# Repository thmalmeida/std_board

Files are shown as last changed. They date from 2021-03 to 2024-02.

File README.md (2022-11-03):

# std_board
_std_board_ is an open hardware project that aims to bring the connectivity capacity of a microcontroller joining with sensors and actuators to a remote monitoring and control.

Renderized PCB with electrical components and modules are showed on the following picture.
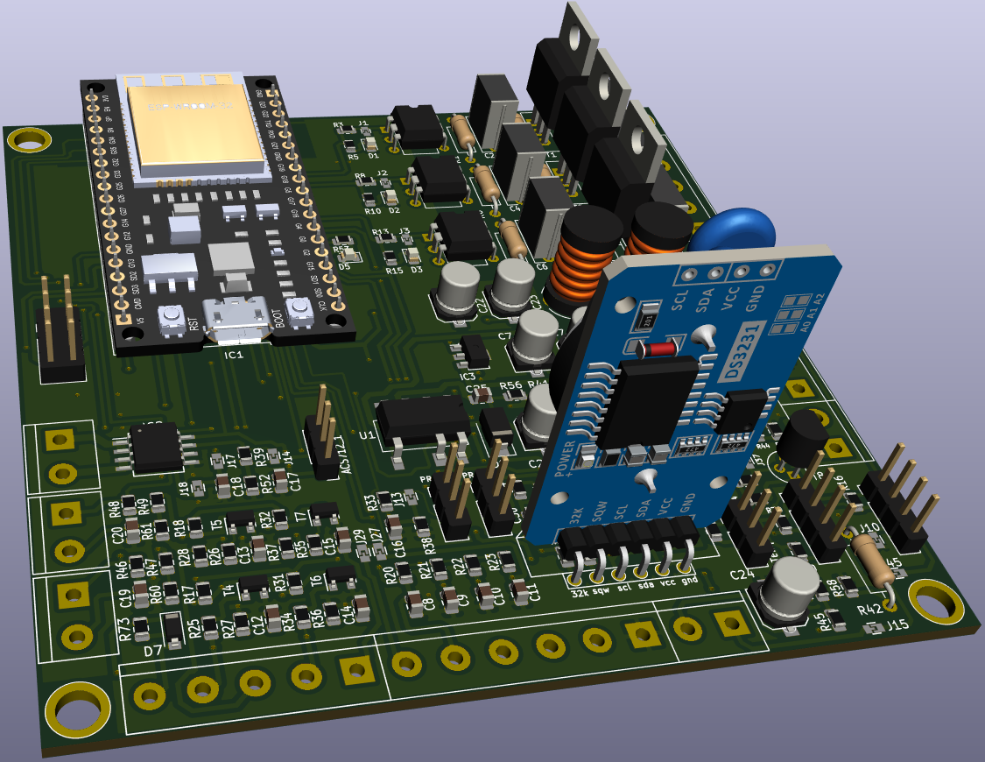
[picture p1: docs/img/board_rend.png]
std_board_img03


# update logs

- 20210901
  + Voltage divider resistor values has been calculated sucessfully;
  + AC voltage measure sensor simulation has updated for 127 and 220 Vrms;
  + 

- 20210719
 - Fix voltage measure circuit on R58;
 - Modify voltage measure input borne to left side board avoid AC DC short circuits

# Content

* [About std_board](#about-std_board)
* [Features](#features)
* [Peripherals mapping](#peripherals-mapping)
* [Digital inputs](#digitadigitall-inputs)
* [Level sensor](#level-sensor)
* [Voltage sensor](#voltage-sensor)
* [Power input modes](#power_input_modes)
  + [Mode 1: 120-240 VAC input](#mode-1-120-240-vac-input)
  + [Mode 2: 24 VAC input](#mode-2-24-vac-input)
  + [Mode 3: 5 Vdc (external power supply)](#mode-3-5V)
* [Current controller](#current-controller)
* [AC load drive](#ac-load-drive)
* [Erros fixed on v0.1.0](#erros)

## About std_board

The main idea of std_board is help farmers to optimize production and monitoring some variables. Even this hardware is a little bit generic pplication that can control water pumps, valves, solenoids and any AC load. For this, it needs some feedback o real world physical variables like water weel level, time, water pressure inside pumps, ac voltage, ac current, thermal relay, and any digital input. The general purpose is optimize the production controlling the water flux.

The main concept of this system is interfaces one processor, e.g. ESP32, with electrical AC loads and physical parameters.
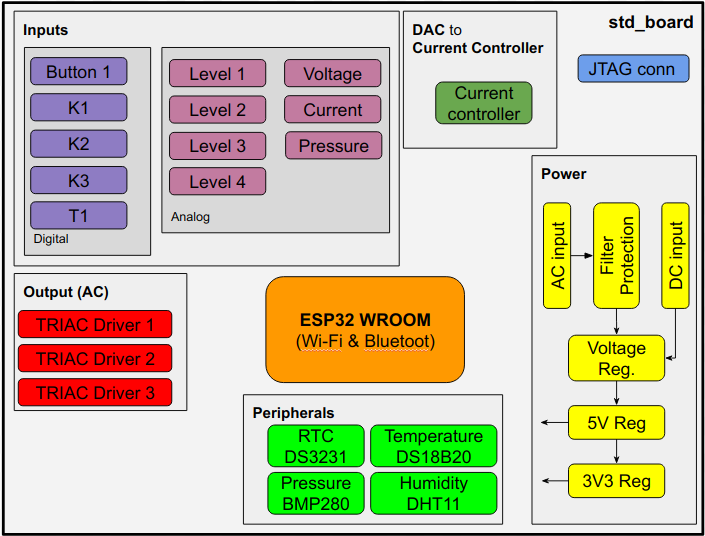
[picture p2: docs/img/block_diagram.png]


## Peripherals mapping

Pin map table of ESP32 onboard connections
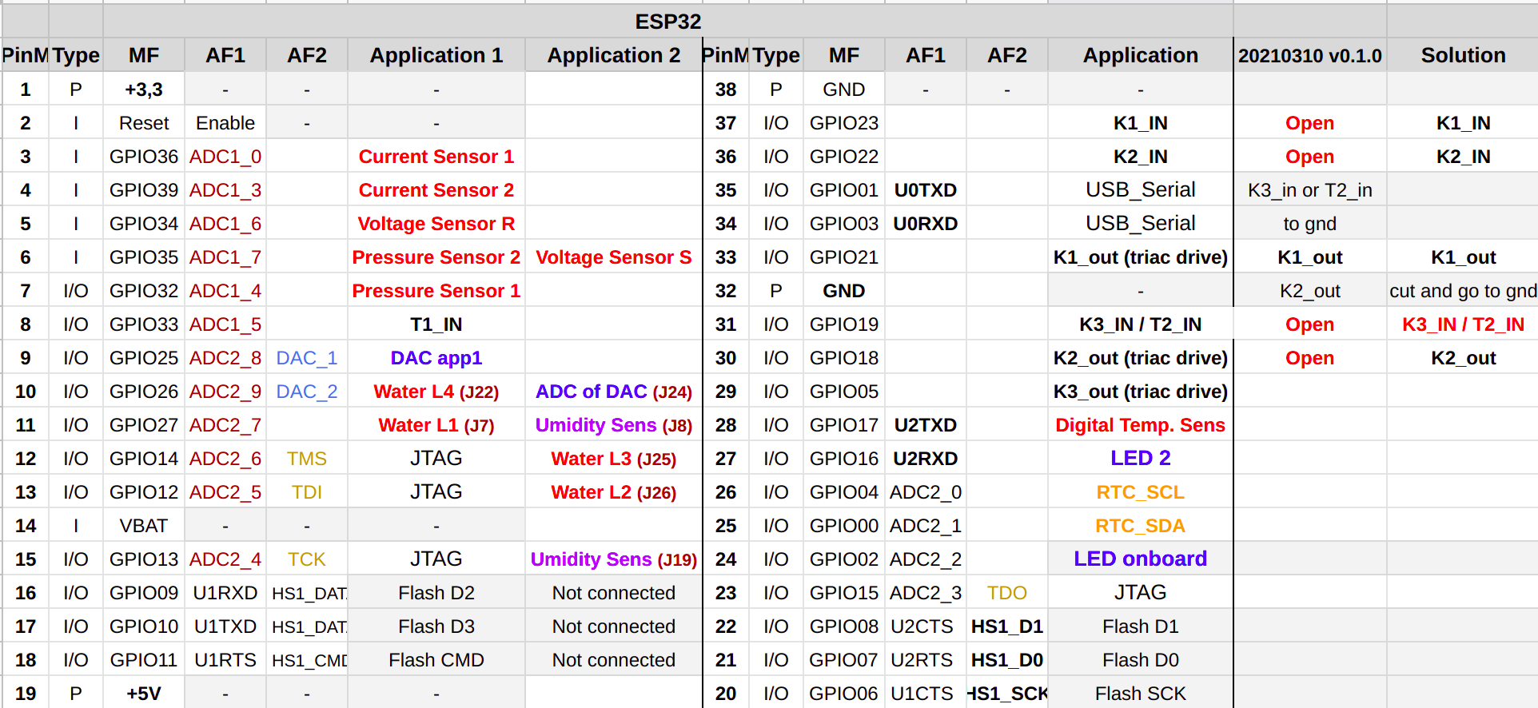
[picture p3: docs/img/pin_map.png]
.

The onboard system has the following connectivities:
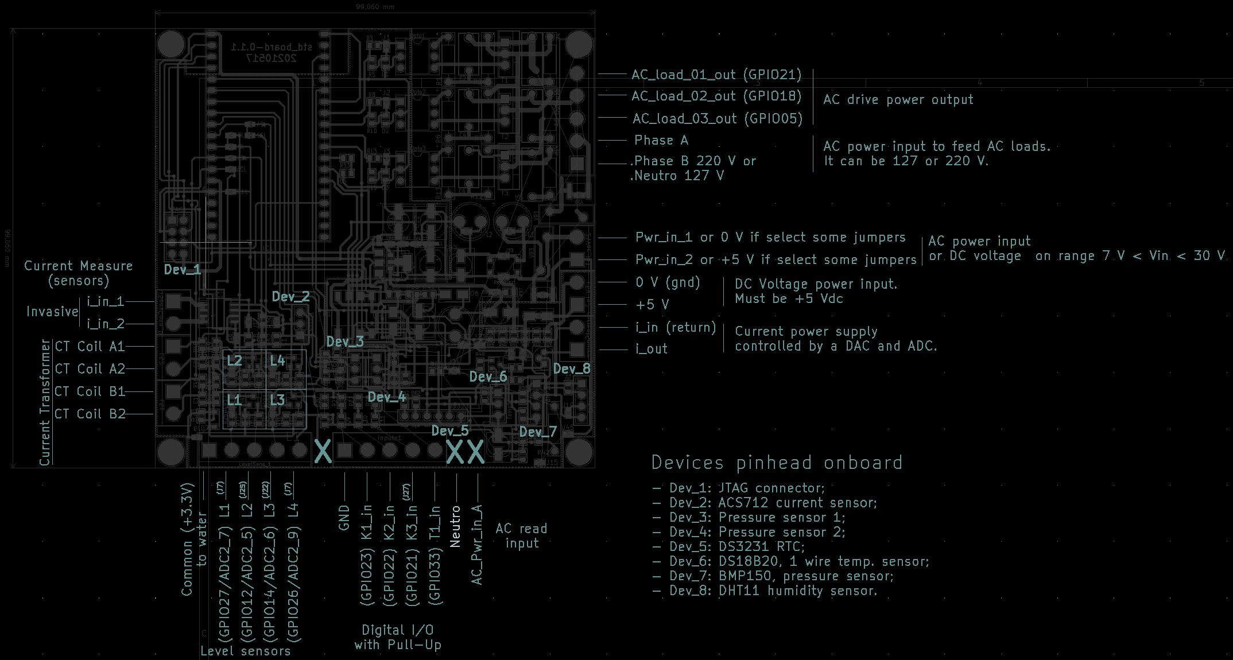
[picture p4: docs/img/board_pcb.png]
std_board_img02


## Features
This board has few hardware printed circuits that interfaces the ESP32 with real world variables conditioning physical variables to low voltages signals readable for input micro controller.

* Digital I/O (four)
* Input for pressure sensor;
* Input for temperature one wire temperature sensor (e.g. DS18B20);
* Umidity sensor DHT11;
* Current controller using internal DAC and onboard circuit processing;
* Protection circuit;
* AC voltage sensor;
* AC current sensor;
* AC load drive;
* JTAG connector - for debbugger (e.g. FT2232H);
* I2C connection for RTC module (e.g. DS3231);
* I2C connection for barometric sensor (e.g. BMP280);
* Four independent water level sensor circuits;
* Onboard LED indicator;
* Power supply with capability with different voltage levels input;

### Digital I/O

Four digital I/O are mounted with 56 kOhms pull up resistors and low pass filter using 47 nF capactitor. The circuit are showing on the following Figure.

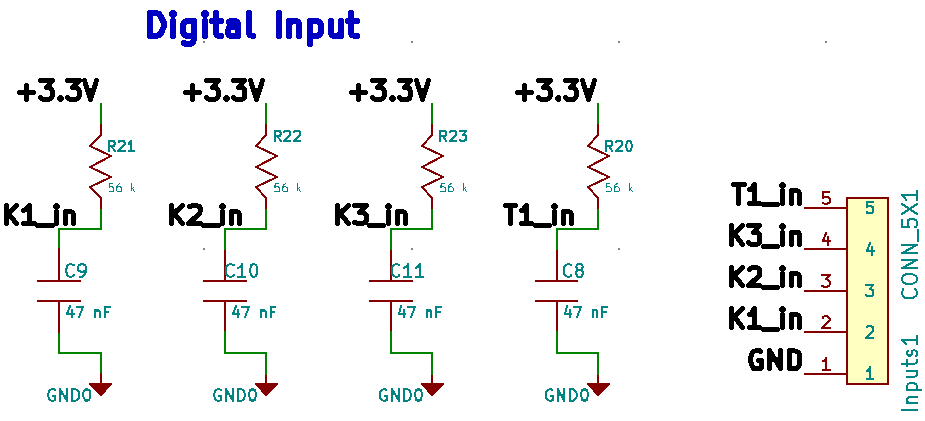
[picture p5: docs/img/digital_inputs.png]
Image of main window on linux


### Level sensor

This board has four independent water level sensor circuit. Each circuit uses one BJT (bipolar junction transistor) and has one jump to exclude this transistor if desired. The main concept of this circuit a voltage division with amplification. The transistor has the function to amplifier the signal and transform it in a digital.

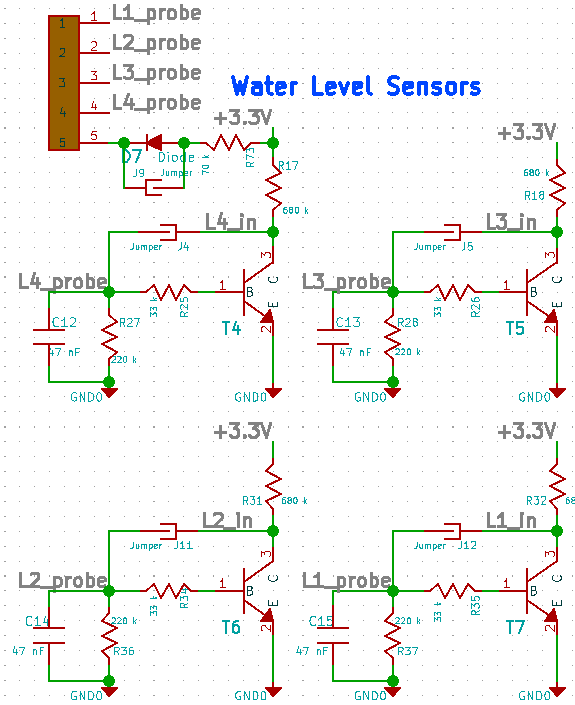
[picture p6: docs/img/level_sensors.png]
Level_Sensors_img01 Water level sensor schematic circuit


Some simulation has been done

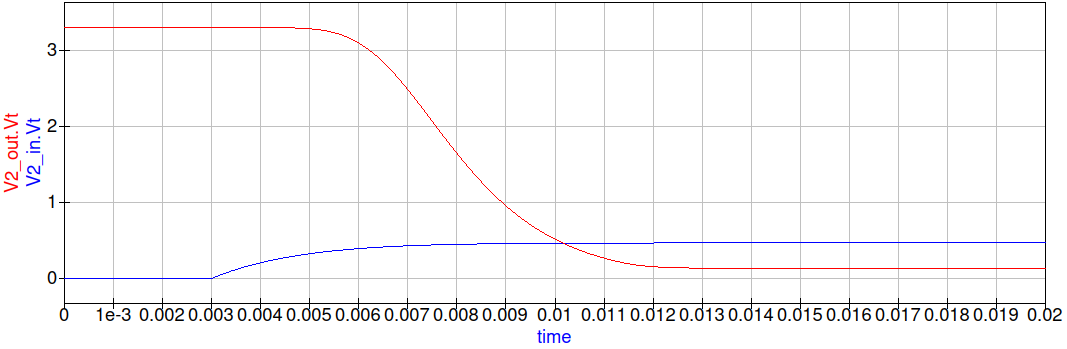
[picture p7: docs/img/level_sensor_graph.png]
Level_Sensors_img02 Time domain input and output voltage level


## Voltage sensor
The voltage sensor can measure four different source of voltages into one selected soldering jump. The following Figure shows the schematic of voltage sensor circuit.

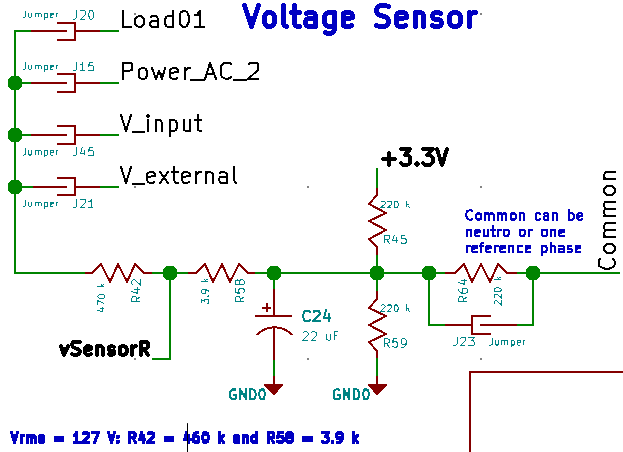
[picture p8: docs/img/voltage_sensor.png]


## Power input modes

### Mode 1: 120-240 VAC input
This mode
to 12VDC and 120 mA;
### Mode 2: 24 VAC to 5 VDC;
20211012 - This mode should be defined, calculated e design in a future moment. Linear regulation has a big waste on drop difference voltage when the input is ~40 V. Bests solutions were found using switching regulators. LNK30x series has bigger input AC voltage. Some candidates with low voltages are:

- LM2576
- LM2596
- DPA422GN
- XL7015

Switches regulators has best efficiency when drop difference voltage are considerable.

### Mode 3: 5 Vdc (external power supply)

If the system is powered with external 5 V power supply on Pwr_in_1 (0V) and Pwr_in_2 (+5V), it needs to solder some following jumps:

- J31: to jump F3 fuse;
- J32: to jump L1 protection inductor;
- J33 and J43: to jump rectifer 1;
- J40: to jump L2 filter;
- J41: link node A with node B;
- J44: link node B to node C;
- J42: jump 5 V regulation because it's powered directly with external 5 V;
- J35: to link the 5 V with whole system;

## Current controller

## AC load drive

This boards has three circuits to drive AC voltage from source to the load using TRIAC and optocoupler components. Some filters to avoid unexpected shots are implemented on the power side. The Figure bellow shows the drive where one high logic digital signal from +3,3 V to +5 V can be applied on <em>K1_out</em> point and shotting the TRIAC. The <em>Power_AC_2</em> is the main phase that drives throug the TRIAC to de <em>Load1</em> node. This load must be connected to another phase or to neutro to make a close circuit.

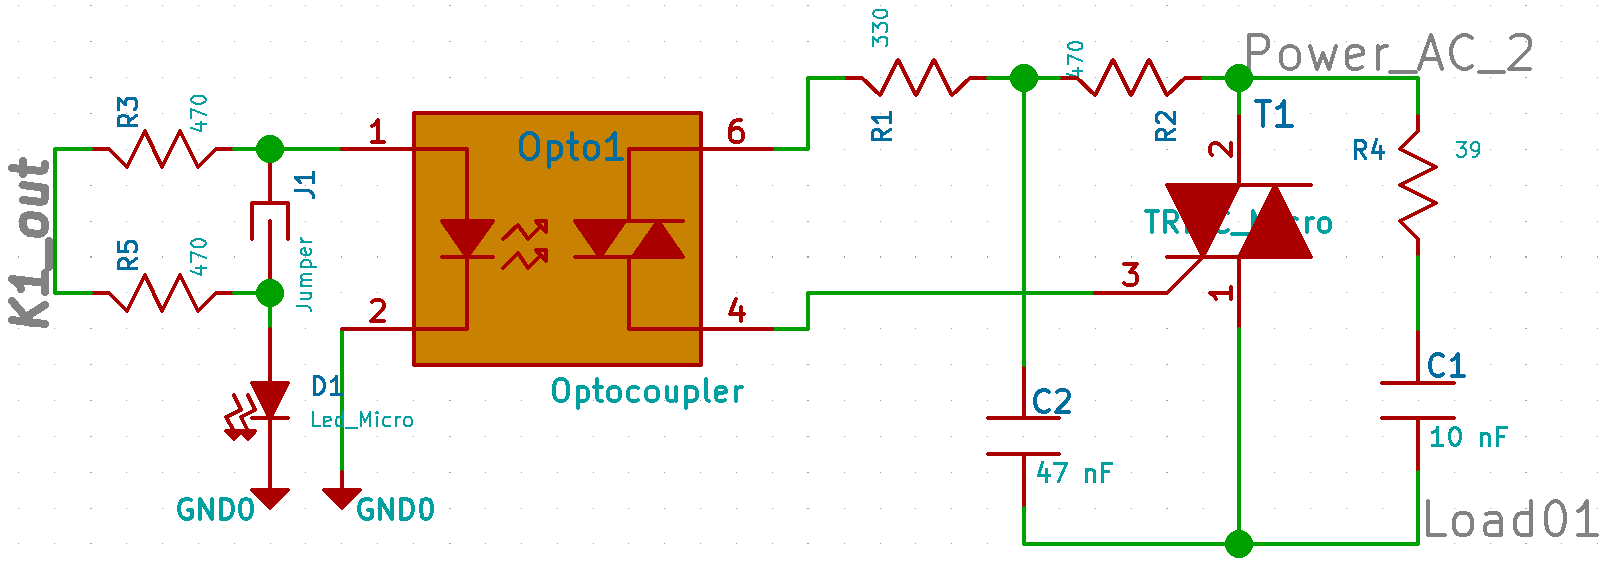
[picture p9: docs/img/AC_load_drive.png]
AC_load_drive AC Load drive


It needs to put a F1 fuse or solder J36 jump.

# Setup #1 on 0.1.0 version (20210310):

This part guide to build one setup to common use. The nexts steps should be followed to connect jumps to link electrical parts.

- J9: connect the common pad wire to 3.3V on water level circuits;
- R73: can be short circuited
- J27: exclude the first pad and connect T1 input to fifth pad;
- J16: substitute abstract diode D4 protection;
- J25: solder jump to connect L3 water level using GPIO14;
- J26: solder jump to connect L2 water level using GPIO12;
- J19: connect umidity sensor on GPIO13;

- Current source drive circuit
Should solder J24 to use ADC read on GPIO26 into ADC2_9;

## Hardware mounted onboard

* Pressure circuit bias 1;
* Pressure circuit bias 2;

# Setup #2

# Setup #3

# Tips
To use L1 and L4 circuit level sensor should solder the following jumps:

L1: put jump J22 closed;
L4: put jump J7 closed;

# Errors

- Voltage sensor

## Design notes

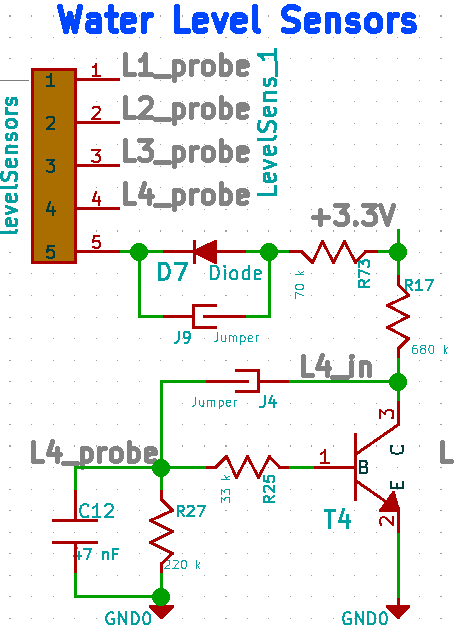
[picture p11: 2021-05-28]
docs/img/Screenshot from 2021-04-19 16-40-09.png

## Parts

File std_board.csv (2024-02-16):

Source: | /home/thmalmeida/Acervo/data/circuits/ESP32/design/std_board/std_board.kicad_sch
Date: | dom 11 fev 2024 19:25:42
Tool: | Eeschema 7.0.10-7.0.10~ubuntu22.04.1
Generator: | /usr/share/kicad/plugins/bom_csv_grouped_by_value.py
Component Count: | 214
Collated Components:
Item | Qty | Reference(s) | Value | LibPart | Footprint | Datasheet | DNP | Manufacture | Manufacturer | Module | Part Number | Partnumber | Placed Onboard? | Rated Current [A] | Rated Power [W] | Rated Power [W] | Rated Voltage [V] | Reverse voltage [V] | Sim.Device | Sim.Params | Sim.Pins | Technical Manual | Tolerance [%] | manf#
1 | 1 | 24Vac_In1 | PowerSupply | std_board-rescue:Connector_2-thmalmeida | TerminalBlock:TerminalBlock_bornier-2_P5.08mm
2 | 1 | +5V_In2 | +5V | std_board-rescue:Conn_2_thm-thmalmeida | TerminalBlock:TerminalBlock_bornier-2_P5.08mm
3 | 2 | AC_Output1, AC_Output2 | Driver_AC_1 | std_board-rescue:CONN_6X1-thmalmeida | TerminalBlock:TerminalBlock_bornier-6_P5.08mm
4 | 1 | ACS712_1 | ACS712_Module | std_board-rescue:CONN_3X1-thmalmeida | Connector_PinHeader_2.54mm:PinHeader_1x03_P2.54mm_Vertical
5 | 1 | BMP280_1 | BMP280 | std_board-rescue:CONN_4X1-thmalmeida | Pin_Headers:Pin_Header_Straight_1x04_Pitch2.54mm |  |  |  | MM | mm | xxxx |  | no
6 | 4 | C1, C3, C5, C32 | 10 nF | std_board-rescue:C_Micro-RESCUE-[GenericBoard]_standard_pcb-[GenericBoard]-standard-pcb-rescue | Capacitor_THT:C_Rect_L11.5mm_W4.3mm_P10.00mm_MKT |  |  | yyyy |  | xxx | xxxx |  | yes |  |  |  | xx
7 | 4 | C2, C4, C6, C31 | 47 nF | std_board-rescue:C_Micro-RESCUE-[GenericBoard]_standard_pcb-[GenericBoard]-standard-pcb-rescue | Capacitor_THT:C_Rect_L9.0mm_W4.2mm_P7.50mm_MKT |  |  | yyyy |  | xxx | xxxx |  | yes |  |  |  | xx
8 | 1 | C7 | 47 uF | std_board-rescue:CP_Micro-thmalmeida | thmalmeida:C3_elec_5x4.5_pth |  |  |  | mmmm | MM | pppp |  | yes |  |  |  | vv |  |  |  |  |  | 10
9 | 5 | C8, C9, C10, C11, C22 | 47 nF | std_board-rescue:C_Micro-RESCUE-[GenericBoard]_standard_pcb-[GenericBoard]-standard-pcb-rescue | Capacitor_SMD:C_0805_2012Metric |  |  | yyyy |  | xxx | xxxx |  | yes |  |  |  | xx
10 | 6 | C12, C13, C14, C15, C16, C30 | 10 nF | std_board-rescue:C_Micro-RESCUE-[GenericBoard]_standard_pcb-[GenericBoard]-standard-pcb-rescue | Capacitor_SMD:C_0805_2012Metric |  |  | yyyy |  | xxx | xxxx |  | yes |  |  |  | xx
11 | 1 | C17 | 0.1 uF | std_board-rescue:C_Micro-RESCUE-[GenericBoard]_standard_pcb-[GenericBoard]-standard-pcb-rescue | Capacitor_SMD:C_0805_2012Metric |  |  | yyyy |  | xxx | xxxx |  | yes |  |  |  | xx
12 | 1 | C18 | 1 nF | std_board-rescue:C_Micro-RESCUE-[GenericBoard]_standard_pcb-[GenericBoard]-standard-pcb-rescue | Capacitor_SMD:C_0805_2012Metric |  |  | yyyy |  | xxx | xxxx |  | yes |  |  |  | xx
13 | 4 | C19, C20, C21, C28 | 1 uF | std_board-rescue:C_Micro-RESCUE-[GenericBoard]_standard_pcb-[GenericBoard]-standard-pcb-rescue | Capacitor_SMD:C_0805_2012Metric |  |  | yyyy |  | xxx | xxxx |  | yes |  |  |  | xx
14 | 1 | C24 | 22 uF | std_board-rescue:CP_Micro-thmalmeida | thmalmeida:C3_elec_5x4.5_pth |  |  |  | mmmm | MM | pppp |  | yes |  |  |  | vv |  |  |  |  |  | 10
15 | 1 | C25 | 100 nF | std_board-rescue:C_Micro-RESCUE-[GenericBoard]_standard_pcb-[GenericBoard]-standard-pcb-rescue | Capacitor_SMD:C_0805_2012Metric |  |  | yyyy |  | xxx | xxxx |  | yes |  |  |  | xx
16 | 1 | C26 | 10 uF | std_board-rescue:CP_Micro-thmalmeida | thmalmeida:C3_elec_5x4.5_pth |  |  |  | mmmm | MM | pppp |  | yes |  |  |  | vv |  |  |  |  |  | 10
17 | 1 | C27 | 4.7 uF | std_board-rescue:CP_Micro-thmalmeida | thmalmeida:C3_elec_5x4.5_pth |  |  |  | mmmm | MM | pppp |  | yes |  |  |  | vv |  |  |  |  |  | 10
18 | 1 | C29 | 100 uF | std_board-rescue:CP_Micro-thmalmeida | thmalmeida:C3_elec_5x4.5_pth |  |  |  | mmmm | MM | pppp |  | yes |  |  |  | vv |  |  |  |  |  | 10
19 | 1 | Conn1 | NOKIA5110 | thmalmeida:CONN_8X1 | Pin_Headers:Pin_Header_Straight_1x08_Pitch2.54mm
20 | 1 | currentSource_1 | Connector_2 | std_board-rescue:Connector_2-thmalmeida | TerminalBlock:TerminalBlock_bornier-2_P5.08mm
21 | 5 | D1, D2, D3, D5, D8 | Led_Micro | std_board-rescue:Led_Micro-thmalmeida | LEDs:LED-5MM |  |  |  | MM | mmmm | pppp |  | yes |  | 1 m
22 | 1 | D4 | Diode | std_board-rescue:Diode-thmalmeida | Diode_SMD:D_SMA |  |  |  | MM | mmmm | xxxx |  | yes | 10 |  |  |  | 350
23 | 1 | D6 | 1N4005GP | std_board-rescue:Diode-thmalmeida | Diode_SMD:D_SMA |  |  |  | MM | mmmm | xxxx |  | yes | 10 |  |  |  | 350
24 | 1 | D7 | Diode | std_board-rescue:Diode-thmalmeida | Diode_SMD:D_SOD-123 |  |  |  | MM | mmmm | xxxx |  | yes | 10 |  |  |  | 350
25 | 1 | D9 | UF4005 | std_board-rescue:Diode-thmalmeida | Diode_SMD:D_SMA |  |  |  | MM | mmmm | xxxx |  | yes | 10 |  |  |  | 350
26 | 5 | DHT11_1, DHT11_2, DHT11_3, DHT11_4, DHT11_5 | DHT11 | std_board-rescue:CONN_4X1-thmalmeida | Pin_Headers:Pin_Header_Straight_1x04_Pitch2.54mm |  |  |  | MM | mm | xxxx |  | no
27 | 1 | DS3231_1 | DS3231_1 | std_board-rescue:CONN_6X1-thmalmeida-std_board-rescue | Pin_Headers:Pin_Header_Straight_1x06
28 | 4 | E1, E2, E3, E4 | ScrewHole | std_board-rescue:ScrewHole-thmalmeida | thmalmeida:ScrewHole_4.2mm
29 | 1 | F1 | Fuse | std_board-rescue:Fuse-thmalmeida | Resistors_SMD:R_1812 |  |  |  | VISHAY | xx | MSMD0805-050 |  | yes | 0.5 |  |  | 6
30 | 1 | F3 | Fuse | :Fuse-thmalmeida_1 | Resistors_SMD:R_1812 |  |  |  | VISHAY | xx | MSMD0805-050 |  | yes | 0.5 |  |  | 6
31 | 1 | IC1 | ESP32 | thmalmeida:ESP32 | thmalmeida:ESP32_DEVKIT | https://www.espressif.com/sites/default/files/documentation/esp32_datasheet_en.pdf |  |  | Espressif |  |  | ESP-WROOM-32 |  |  |  |  |  |  |  |  |  | https://www.espressif.com/sites/default/files/documentation/esp32_technical_reference_manual_en.pdf
32 | 1 | IC2 | ACS712 | std_board-rescue:ACS712-thmalmeida | Housings_SOIC:SOIC-8_3.9x4.9mm_Pitch1.27mm |  |  |  | Allegro | xx | ACS712 |  | yes | 20
33 | 1 | Inputs1 | CONN_5X1 | std_board-rescue:CONN_5X1-thmalmeida | TerminalBlock:TerminalBlock_bornier-5_P5.08mm
34 | 1 | iSensConn_0 | sensConn | std_board-rescue:Connector_2-thmalmeida | TerminalBlock:TerminalBlock_bornier-2_P5.08mm
35 | 38 | J1, J2, J3, J4, J5, J6, J7, J8, J9, J11, J12, J13, J14, J15, J17, J18, J19, J20, J21, J22, J23, J24, J25, J26, J31, J32, J33, J34, J36, J37, J38, J39, J40, J41, J42, J43, J44, J45 | Jumper | std_board-rescue:Jumper-thmalmeida | thmalmeida:J_0603 |  |  |  |  |  |  |  |  |  |  |  |  |  | SPICE | type="X" model="Jumper" lib="" | 1=1 2=2
36 | 1 | J10 | J_DHT11 | std_board-rescue:Jumper-thmalmeida | thmalmeida:J_0603
37 | 1 | J16 | J_PRess | std_board-rescue:Jumper-thmalmeida | thmalmeida:J_0603
38 | 1 | JTAG1 | JTAG_CONN-06_adapted | std_board-rescue:JTAG_CONN-06_adapted-thmalmeida | Connector_PinHeader_2.54mm:PinHeader_2x04_P2.54mm_Vertical
39 | 2 | L1, L2 | L_Micro | std_board-rescue:L_Micro-thmalmeida | Inductor_THT:L_Radial_D7.5mm_P5.00mm_Fastron_07P |  |  | yyyy |  | xxx | xxxx |  | yes |  |  |  | xx |  |  |  |  |  | xx
40 | 1 | L4 | 1 mH | std_board-rescue:L_Micro-thmalmeida | Inductor_THT:L_Radial_D7.5mm_P5.00mm_Fastron_07P |  |  | yyyy |  | xxx | xxxx |  | yes |  |  |  | xx |  |  |  |  |  | xx
41 | 1 | LevelSens_1 | levelSensors | std_board-rescue:CONN_5X1-thmalmeida | TerminalBlock:TerminalBlock_bornier-5_P5.08mm
42 | 2 | LS1, LS2 | I_sens | std_board-rescue:I_sens-thmalmeida | Connector_PinHeader_2.54mm:PinHeader_1x02_P2.54mm_Horizontal |  |  |  | MMMM | MMMM | pppp |  | yes | I
43 | 3 | Opto1, Opto2, Opto3 | Optocoupler | std_board-rescue:Optocoupler-thmalmeida | Housings_DIP:DIP-6_W7.62mm |  |  |  | MMMM |  | xxxx |  | yes |  |  |  |  |  |  |  |  |  |  | MOC3021M
44 | 1 | Opto4 | Optocoupler | std_board-rescue:Optocoupler-thmalmeida | Package_DIP:DIP-6_W7.62mm |  |  |  | MMMM |  | xxxx |  | yes
45 | 2 | PRess1, PRess2 | pressureSensor | std_board-rescue:CONN_3X1-thmalmeida | Connector_PinHeader_2.54mm:PinHeader_1x03_P2.54mm_Vertical
46 | 2 | R1, R69 | 330 | std_board-rescue:R_Micro-thmalmeida | Resistor_THT:R_Axial_DIN0207_L6.3mm_D2.5mm_P7.62mm_Horizontal |  |  |  | VISHAY | xx | MCT08050F1001C |  | yes |  |  | 0.1 |  |  |  |  |  |  | 5
47 | 2 | R2, R70 | 470 | std_board-rescue:R_Micro-thmalmeida | Resistor_THT:R_Axial_DIN0207_L6.3mm_D2.5mm_P7.62mm_Horizontal |  |  |  | VISHAY | xx | MCT08050F1001C |  | yes |  |  | 0.1 |  |  |  |  |  |  | 5
48 | 4 | R3, R8, R13, R67 | 680 | std_board-rescue:R_Micro-thmalmeida | Resistor_SMD:R_0805_2012Metric |  |  |  | VISHAY | xx | MCT08050F1001C |  | yes |  |  | 0.1 |  |  |  |  |  |  | 5
49 | 2 | R4, R71 | 39 | std_board-rescue:R_Micro-thmalmeida | Resistor_SMD:R_0805_2012Metric |  |  |  | VISHAY | xx | MCT08050F1001C |  | yes |  |  | 0.1 |  |  |  |  |  |  | 5
50 | 4 | R5, R10, R15, R68 | 1 k | std_board-rescue:R_Micro-thmalmeida | Resistor_SMD:R_0805_2012Metric |  |  |  | VISHAY | xx | MCT08050F1001C |  | yes |  |  | 0.1 |  |  |  |  |  |  | 5
51 | 2 | R6, R11 | 360 | std_board-rescue:R_Micro-thmalmeida | Resistor_SMD:R_0805_2012Metric |  |  |  | VISHAY | xx | MCT08050F1001C |  | yes |  |  | 0.1 |  |  |  |  |  |  | 5
52 | 2 | R7, R12 | 470 | std_board-rescue:R_Micro-thmalmeida | Resistor_SMD:R_0805_2012Metric |  |  |  | VISHAY | xx | MCT08050F1001C |  | yes |  |  | 0.1 |  |  |  |  |  |  | 5
53 | 2 | R9, R14 | 47 | std_board-rescue:R_Micro-thmalmeida | Resistor_SMD:R_0805_2012Metric |  |  |  | VISHAY | xx | MCT08050F1001C |  | yes |  |  | 0.1 |  |  |  |  |  |  | 5
54 | 2 | R16, R76 | 4.7 k | std_board-rescue:R_Micro-thmalmeida | Resistor_SMD:R_0805_2012Metric |  |  |  | VISHAY | xx | MCT08050F1001C |  | yes |  |  | 0.1 |  |  |  |  |  |  | 5
55 | 4 | R17, R18, R31, R32 | 560 k | std_board-rescue:R_Micro-thmalmeida | Resistor_SMD:R_0805_2012Metric |  |  |  | VISHAY | xx | MCT08050F1001C |  | yes |  |  | 0.1 |  |  |  |  |  |  | 5
56 | 1 | R19 | 47 k | std_board-rescue:R_Micro-thmalmeida | Resistor_SMD:R_0805_2012Metric |  |  |  | VISHAY | xx | MCT08050F1001C |  | yes |  |  | 0.1 |  |  |  |  |  |  | 5
57 | 6 | R20, R21, R22, R23, R47, R72 | 56 k | std_board-rescue:R_Micro-thmalmeida | Resistor_SMD:R_0805_2012Metric |  |  |  | VISHAY | xx | MCT08050F1001C |  | yes |  |  | 0.1 |  |  |  |  |  |  | 5
58 | 2 | R24, R39 | 2.2 k | std_board-rescue:R_Micro-thmalmeida | Resistor_SMD:R_0805_2012Metric |  |  |  | VISHAY | xx | MCT08050F1001C |  | yes |  |  | 0.1 |  |  |  |  |  |  | 5
59 | 4 | R25, R26, R34, R35 | 33 k | std_board-rescue:R_Micro-thmalmeida | Resistor_SMD:R_0805_2012Metric |  |  |  | VISHAY | xx | MCT08050F1001C |  | yes |  |  | 0.1 |  |  |  |  |  |  | 5
60 | 5 | R27, R28, R36, R37, R64 | 220 k | std_board-rescue:R_Micro-thmalmeida | Resistor_SMD:R_0805_2012Metric |  |  |  | VISHAY | xx | MCT08050F1001C |  | yes |  |  | 0.1 |  |  |  |  |  |  | 5
61 | 2 | R29, R30 | R_Micro | std_board-rescue:R_Micro-thmalmeida | Resistor_SMD:R_0805_2012Metric |  |  |  | VISHAY | xx | MCT08050F1001C |  | yes |  |  | 0.1 |  |  |  |  |  |  | 5
62 | 2 | R33, R74 | 12 k | std_board-rescue:R_Micro-thmalmeida | Resistor_SMD:R_0805_2012Metric |  |  |  | VISHAY | xx | MCT08050F1001C |  | yes |  |  | 0.1 |  |  |  |  |  |  | 5
63 | 4 | R38, R65, R66, R75 | 6.8 k | std_board-rescue:R_Micro-thmalmeida | Resistor_SMD:R_0805_2012Metric |  |  |  | VISHAY | xx | MCT08050F1001C |  | yes |  |  | 0.1 |  |  |  |  |  |  | 5
64 | 1 | R40 | 100 k | std_board-rescue:R_Micro-thmalmeida | Resistor_SMD:R_0805_2012Metric |  |  |  | VISHAY | xx | MCT08050F1001C |  | yes |  |  | 0.1 |  |  |  |  |  |  | 5
65 | 1 | R41 | 13 k | std_board-rescue:R_Micro-thmalmeida | Resistor_SMD:R_0805_2012Metric |  |  |  | VISHAY | xx | MCT08050F1001C |  | yes |  |  | 0.1 |  |  |  |  |  |  | 5
66 | 1 | R42 | 1 M | std_board-rescue:R_Micro-thmalmeida | Resistor_SMD:R_0805_2012Metric |  |  |  | VISHAY | xx | MCT08050F1001C |  | yes |  |  | 0.1 |  |  |  |  |  |  | 5
67 | 6 | R43, R44, R50, R51, R54, R55 | 30 | std_board-rescue:R_Micro-thmalmeida | Resistor_SMD:R_0805_2012Metric |  |  |  | VISHAY | xx | MCT08050F1001C |  | yes |  |  | 0.1 |  |  |  |  |  |  | 5
68 | 2 | R45, R60 | 39 k | std_board-rescue:R_Micro-thmalmeida | Resistor_SMD:R_0805_2012Metric |  |  |  | VISHAY | xx | MCT08050F1001C |  | yes |  |  | 0.1 |  |  |  |  |  |  | 5
69 | 5 | R46, R48, R52, R57, R58 | 3.3 k | std_board-rescue:R_Micro-thmalmeida | Resistor_SMD:R_0805_2012Metric |  |  |  | VISHAY | xx | MCT08050F1001C |  | yes |  |  | 0.1 |  |  |  |  |  |  | 5
70 | 1 | R49 | 180 k | std_board-rescue:R_Micro-thmalmeida | Resistor_SMD:R_0805_2012Metric |  |  |  | VISHAY | xx | MCT08050F1001C |  | yes |  |  | 0.1 |  |  |  |  |  |  | 5
71 | 1 | R53 | 510 | std_board-rescue:R_Micro-thmalmeida | Resistor_SMD:R_0805_2012Metric |  |  |  | VISHAY | xx | MCT08050F1001C |  | yes |  |  | 0.1 |  |  |  |  |  |  | 5
72 | 1 | R56 | 2.05 k | std_board-rescue:R_Micro-thmalmeida | Resistor_SMD:R_0805_2012Metric |  |  |  | VISHAY | xx | MCT08050F1001C |  | yes |  |  | 0.1 |  |  |  |  |  |  | 5
73 | 2 | R59, R61 | 120 k | std_board-rescue:R_Micro-thmalmeida | Resistor_SMD:R_0805_2012Metric |  |  |  | VISHAY | xx | MCT08050F1001C |  | yes |  |  | 0.1 |  |  |  |  |  |  | 5
74 | 2 | R62, R63 | 10 k | std_board-rescue:R_Micro-thmalmeida | Resistor_SMD:R_0805_2012Metric |  |  |  | VISHAY | xx | MCT08050F1001C |  | yes |  |  | 0.1 |  |  |  |  |  |  | 5
75 | 1 | R73 | 70 k | std_board-rescue:R_Micro-thmalmeida | Resistor_SMD:R_0805_2012Metric |  |  |  | VISHAY | xx | MCT08050F1001C |  | yes |  |  | 0.1 |  |  |  |  |  |  | 5
76 | 5 | R77, R78, R79, R80, R81 | 330 | std_board-rescue:R_Micro-thmalmeida | Resistor_SMD:R_0805_2012Metric |  |  |  | VISHAY | xx | MCT08050F1001C |  | yes |  |  | 0.1 |  |  |  |  |  |  | 5
77 | 1 | Rectifier1 | DF10S | std_board-rescue:Bridge_Rectifier-thmalmeida | Package_TO_SOT_SMD:TO-269AA |  |  |  | MMMM |  | xxxx |  | yes
78 | 2 | T1, T3 | TRIAC_Micro | std_board-rescue:TRIAC_Micro-thmalmeida | Package_TO_SOT_THT:TO-220-3_Vertical |  |  |  | MMMM |  | xxxx |  | yes
79 | 1 | T2 | TRIAC_Micro | std_board-rescue:TRIAC_Micro-thmalmeida | TO_SOT_Packages_THT:TO-220_Neutral123_Vertical |  |  |  | MMMM |  | xxxx |  | yes
80 | 5 | T4, T5, T6, T7, T9 | NPN_MMBT222A | std_board-rescue:NPN-thmalmeida | TO_SOT_Packages_SMD:SOT-23 |  |  |  | mmmm | MM | pppp |  | yes
81 | 1 | T8 | PNP_2N3906 | thmalmeida:PNP_TO-92 | Package_TO_SOT_THT:TO-92 |  |  |  | yyyy |  | xxxx
82 | 1 | T10 | TRIAC_Micro | std_board-rescue:TRIAC_Micro-thmalmeida | thmalmeida:TO-220_thm |  |  |  | MMMM |  | xxxx |  | yes
83 | 1 | Temp1 | DS18B20 | std_board-rescue:CONN_3X1-thmalmeida | Connector_PinHeader_2.54mm:PinHeader_1x03_P2.54mm_Vertical
84 | 1 | U1 | LNK306 | std_board-rescue:LNK306-thmalmeida | Package_DIP:PowerIntegrations_SMD-8B |  |  |  | M |  |  | pppp | yes |  |  |  | 600
85 | 1 | U3 | L7805CV | thmalmeida:L78xxCV | Package_TO_SOT_THT:TO-220-3_Vertical
86 | 2 | VR1, VR3 | VR_Micro | std_board-rescue:VR_Micro-thmalmeida | Varistors:RV_Disc_D12_W3.9_P7.5 |  |  |  | VISHAY | xx | xxxx |  | no |  |  | 0.1 | 120

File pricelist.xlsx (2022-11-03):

Prj: | std_board.xml |  |  |  |  | Board Qty: | 100
Co.: |  |  |  |  |  | Unit Cost: | $0.00
Prj date: | sex 12 nov 2021 16:19:44 |  |  |  |  | Total Cost: | $0.00 |  |  |  |  | $0.00 | 0 of 85 parts found |  |  |  |  | $0.00 | 0 of 85 parts found |  |  |  |  | $0.00 | 0 of 85 parts found |  |  |  |  | $0.00 | 0 of 85 parts found |  |  |  |  | $0.00 | 0 of 85 parts found |  |  |  |  | $0.00 | 0 of 85 parts found |  |  |  |  | $0.00 | 0 of 85 parts found |  |  |  |  | $0.00 | 0 of 85 parts found
$ date: | 2021-11-12 16:19:50
Global Part Info |  |  |  |  |  |  |  | Arrow |  |  |  |  |  | Digi-Key |  |  |  |  |  | Farnell |  |  |  |  |  | LCSC |  |  |  |  |  | Mouser |  |  |  |  |  | Newark |  |  |  |  |  | RS Components |  |  |  |  |  | TME
Refs | Value | Footprint | Manf | Manf# | Qty | Unit$ | Ext$ | Avail | Purch | Unit$ | MOQ | Ext$ | Cat# | Avail | Purch | Unit$ | MOQ | Ext$ | Cat# | Avail | Purch | Unit$ | MOQ | Ext$ | Cat# | Avail | Purch | Unit$ | MOQ | Ext$ | Cat# | Avail | Purch | Unit$ | MOQ | Ext$ | Cat# | Avail | Purch | Unit$ | MOQ | Ext$ | Cat# | Avail | Purch | Unit$ | MOQ | Ext$ | Cat# | Avail | Purch | Unit$ | MOQ | Ext$ | Cat#
+5V_In2 | +5V | TerminalBlock_bornier-2_P5.08mm |  |  | 100
24Vac_In1 | PowerSupply | TerminalBlock_bornier-2_P5.08mm |  |  | 100
ACS712_1 | ACS712_Module | PinHeader_1x03_P2.54mm_Vertical |  |  | 100
AC_Output1 | Driver_AC_1 | TerminalBlock_bornier-6_P5.08mm |  |  | 100
BMP280_1 | BMP280 | PinHeader_1x04_P2.54mm_Vertical | MM |  | 100
C1,C3,C5 | 10 nF | C_Rect_L11.5mm_W4.3mm_P10.00mm_MKT |  |  | 300
C2,C4,C6 | 47 nF | C_Rect_L9.0mm_W4.2mm_P7.50mm_MKT |  |  | 300
C7 | 47 uF | C4_elec_7x6.7_pth | mmmm |  | 100
C8-C11 | 47 nF | C_0805_2012Metric |  |  | 400
C12-C16,C30 | 10 nF | C_0805_2012Metric |  |  | 600
C17 | 0.1 uF | C_0805_2012Metric |  |  | 100
C18 | 1 nF | C_0805_2012Metric |  |  | 100
C19-C21 | 1 uF | C_0805_2012Metric |  |  | 300
C22 | 2.2 uF | C4_elec_7x6.7_pth | mmmm |  | 100
C23 | 22 uF | C4_elec_7x6.7_pth | mmmm |  | 100
C24 | 22 uF | C3_elec_5x4.5_pth | mmmm |  | 100
C25 | 100 nF | C_0805_2012Metric |  |  | 100
C26 | 10 uF | C4_elec_7x6.7_pth | mmmm |  | 100
C27 | 4.7 uF | C3_elec_5x4.5_pth | mmmm |  | 100
C29 | 100 uF | C4_elec_7x6.7_pth | mmmm |  | 100
D1-D3,D5 | Led_Micro | LED_0805_2012Metric | MM |  | 400
D4 | Diode | D_SMA | MM |  | 100
D6 | 1N4005GP | D_SMA | MM |  | 100
D7 | Diode | D_SOD-123 | MM |  | 100
D9 | UF4005 | D_SMA | MM |  | 100
DHT11_1 | DHT11 | PinHeader_1x04_P2.54mm_Vertical | MM |  | 100
DS3231_1 | DS3231_1 | DS3231_module_vertical |  |  | 100
E1-E4 | ScrewHole | ScrewHole_4.2mm |  |  | 400
F1,F3 | Fuse | Fuse_1812_4532Metric | VISHAY |  | 200
IC1 | ESP32 | ESP32_DEVKIT | Espressif | https://www.espressif.com/sites/default/files/documentation/esp32_datasheet_en.pdf | 100
IC2 | ACS712 | SO-8_5.3x6.2mm_P1.27mm | Allegro |  | 100
IC3 | L78L05 | SOT-89-3 | ST |  | 100
IC4 | AMS1117-V | SOT-223 | AMS |  | 100
Inputs1 | CONN_5X1 | TerminalBlock_bornier-5_P5.08mm |  |  | 100
J1-J5,J9,J11,J12,J14,J15,J17-J26,J31-J45 | Jumper | J_0603 |  |  | 3500
J10 | J_DHT11 | J_0603 |  |  | 100
J16 | J_PRess | J_0603 |  |  | 100
JTAG1 | JTAG_CONN-06_adapted | PinHeader_2x04_P2.54mm_Vertical |  |  | 100
L1,L2 | L_Micro | L_Radial_D7.5mm_P5.00mm_Fastron_07P |  |  | 200
L4 | 1 mH | L_Radial_D7.5mm_P5.00mm_Fastron_07P |  |  | 100
LS1,LS2 | I_sens | TerminalBlock_bornier-2_P5.08mm | MMMM |  | 200
LevelSens_1 | levelSensors | TerminalBlock_bornier-5_P5.08mm |  |  | 100
M1 | ADS1x15_module | PinHeader_1x10_P2.54mm_Vertical |  |  | 100
Opto1 | Optocoupler | DIP-6_W7.62mm | MMMM |  | 100
Opto2,Opto3 | Optocoupler | DIP-6_W7.62mm | MMMM | MOC3021M | 200
PRess1,PRess2 | pressureSensor | PinHeader_1x03_P2.54mm_Vertical |  |  | 200
R1 | 330 | R_Axial_DIN0207_L6.3mm_D2.5mm_P10.16mm_Horizontal | VISHAY |  | 100
R2,R7,R12 | 470 | R_Axial_DIN0207_L6.3mm_D2.5mm_P10.16mm_Horizontal | VISHAY |  | 300
R3,R8,R13 | 680 | R_0805_2012Metric | VISHAY |  | 300
R4 | 39 | R_Axial_DIN0207_L6.3mm_D2.5mm_P10.16mm_Horizontal | VISHAY |  | 100
R5,R10,R15 | 1 k | R_0805_2012Metric | VISHAY |  | 300
R6,R11 | 360 | R_Axial_DIN0207_L6.3mm_D2.5mm_P10.16mm_Horizontal | VISHAY |  | 200
R9,R14 | 47 | R_Axial_DIN0207_L6.3mm_D2.5mm_P10.16mm_Horizontal | VISHAY |  | 200
R16,R76 | 4.7 k | R_0805_2012Metric | VISHAY |  | 200
R17,R18,R31,R32 | 560 k | R_0805_2012Metric | VISHAY |  | 400
R19 | 47 k | R_0805_2012Metric | VISHAY |  | 100
R20-R23 | 56 k | R_0805_2012Metric | VISHAY |  | 400
R24,R39 | 2.2 k | R_0805_2012Metric | VISHAY |  | 200
R25,R26,R34,R35 | 33 k | R_0805_2012Metric | VISHAY |  | 400
R27,R28,R36,R37,R64 | 220 k | R_0805_2012Metric | VISHAY |  | 500
R29,R30 | R_Micro | R_0805_2012Metric | VISHAY |  | 200
R33,R74 | 12 k | R_0805_2012Metric | VISHAY |  | 200
R38,R65,R66,R75 | 6.8 k | R_0805_2012Metric | VISHAY |  | 400
R40 | 100 k | R_0805_2012Metric | VISHAY |  | 100
R41 | 13 k | R_0805_2012Metric | VISHAY |  | 100
R42 | 1 M | R_Axial_DIN0207_L6.3mm_D2.5mm_P10.16mm_Horizontal | VISHAY |  | 100
R43,R44,R50,R51,R54,R55 | 30 | R_0805_2012Metric | VISHAY |  | 600
R45,R47,R49 | 180 k | R_0805_2012Metric | VISHAY |  | 300
R46,R48 | 120 | R_0805_2012Metric | VISHAY |  | 200
R52,R57,R58 | 3.3 k | R_0805_2012Metric | VISHAY |  | 300
R53 | 510 | R_0805_2012Metric | VISHAY |  | 100
R56 | 2.05 k | R_0805_2012Metric | VISHAY |  | 100
R59-R61 | 120 k | R_0805_2012Metric | VISHAY |  | 300
R62,R63 | 10 k | R_0805_2012Metric | VISHAY |  | 200
R73 | 70 k | R_0805_2012Metric | VISHAY |  | 100
Rectifier1 | DF10S | TO-269AA | MMMM |  | 100
T1 | TRIAC_Micro | TO-220-3_Vertical | BT136 |  | 100
T2,T3 | TRIAC_Micro | TO-220-3_Vertical | MMMM |  | 200
T4-T7,T9 | NPN_MMBT222A | SOT-23 | mmmm |  | 500
T8 | PNP_2N3906 | TO-92 | yyyy |  | 100
Temp1 | DS18B20 | PinHeader_1x03_P2.54mm_Vertical |  |  | 100
U1 | LNK306 | PowerIntegrations_SMD-8B | M |  | 100
VR1,VR3 | VR_Micro | RV_Disc_D12mm_W3.9mm_P7.5mm | VISHAY |  | 200
currentSource_1 | Connector_2 | TerminalBlock_bornier-2_P5.08mm |  |  | 100
iSensConn_0 | sensConn | TerminalBlock_bornier-2_P5.08mm |  |  | 100
 |  |  |  |  |  | Total Purchase: | $0.00 | Buy here (https://www.arrow.com/en/bom-tool/) |  |  |  | $0.00 |  | Buy here (https://www.digikey.com/ordering/shoppingcart) |  |  |  | $0.00 |  | Buy here (https://fr.farnell.com/en-FR/quick-order?isQuickPaste=true) |  |  |  | $0.00 |  | Buy here (https://lcsc.com/bom.html) |  |  |  | $0.00 |  | Buy here (https://mouser.com/bom/) |  |  |  | $0.00 |  | Buy here (https://www.newark.com/quick-order?isQuickPaste=true) |  |  |  | $0.00 |  | Buy here (https://uk.rs-online.com/web/mylists/manualQuotes.html?method=showEnquiryCreationPage&mode=new) |  |  |  | $0.00 |  | Buy here (https://www.tme.eu/en/Profile/QuickBuy/load.html) |  |  |  | $0.00
KiCost® v1.1.6 |  |  |  |  |  | Purchase description: |  |  |  |  |  |  |  |  |  |  |  |  |  |  |  |  |  |  |  |  | Copy this header and order to a CSV file and use it for JLCPCB manufacturer PCB house. The multipart components that use "#" symbol are not allowed by JLCPCB.

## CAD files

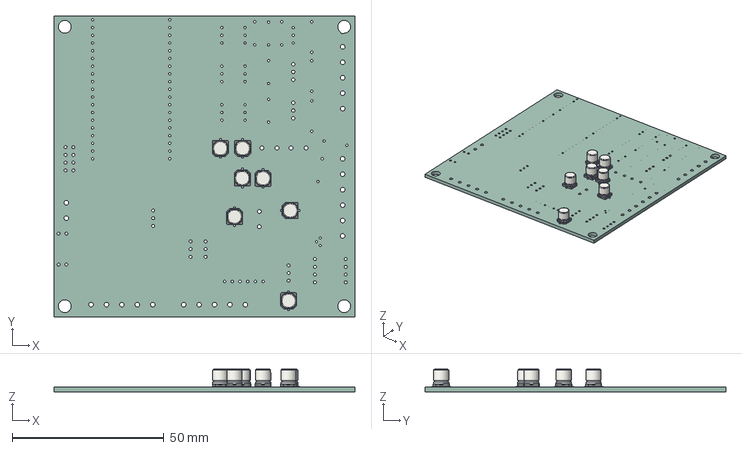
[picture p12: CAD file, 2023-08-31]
std_board.step
99.1 x 99.1 x 7.45 mm
std_board PCB

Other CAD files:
schematic/high_schematic.dxf

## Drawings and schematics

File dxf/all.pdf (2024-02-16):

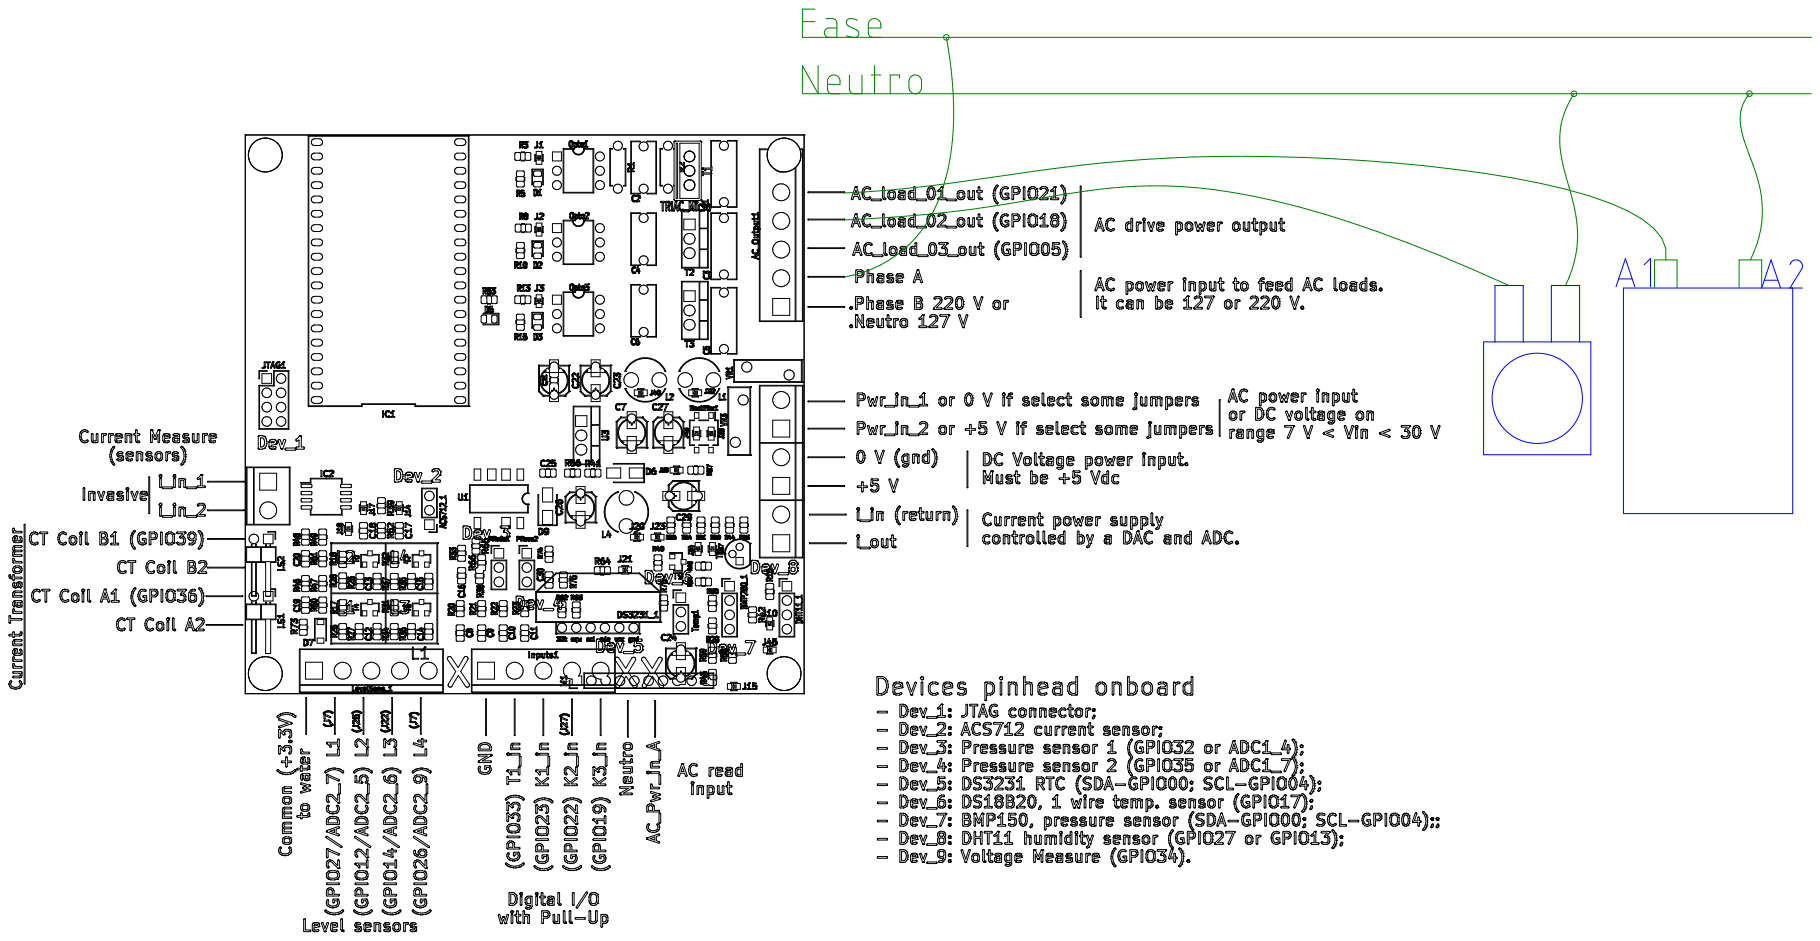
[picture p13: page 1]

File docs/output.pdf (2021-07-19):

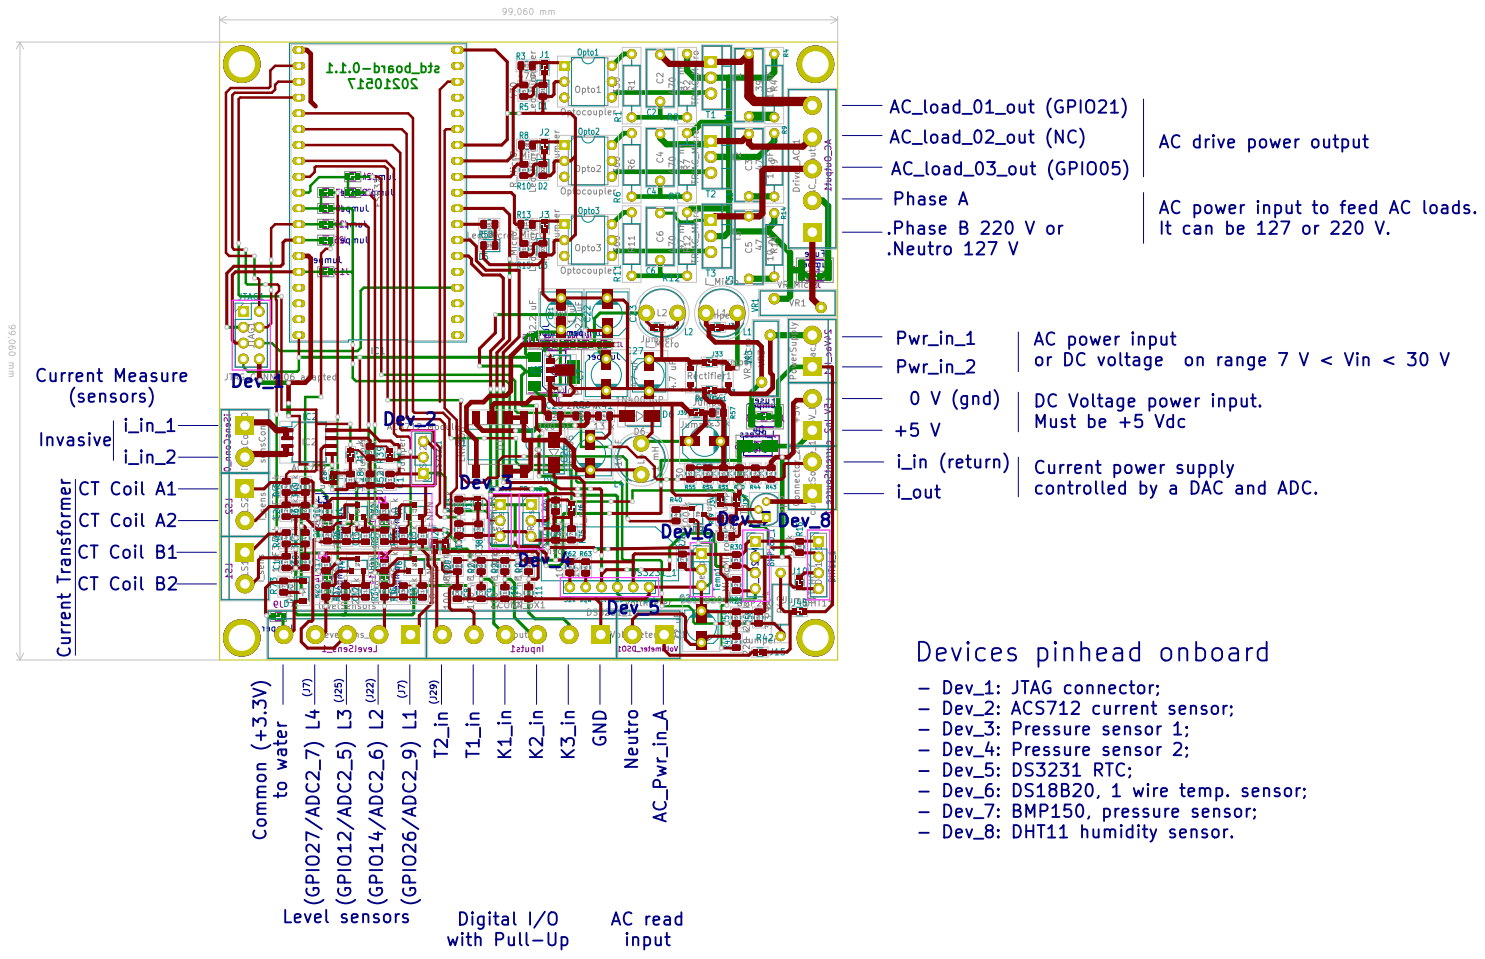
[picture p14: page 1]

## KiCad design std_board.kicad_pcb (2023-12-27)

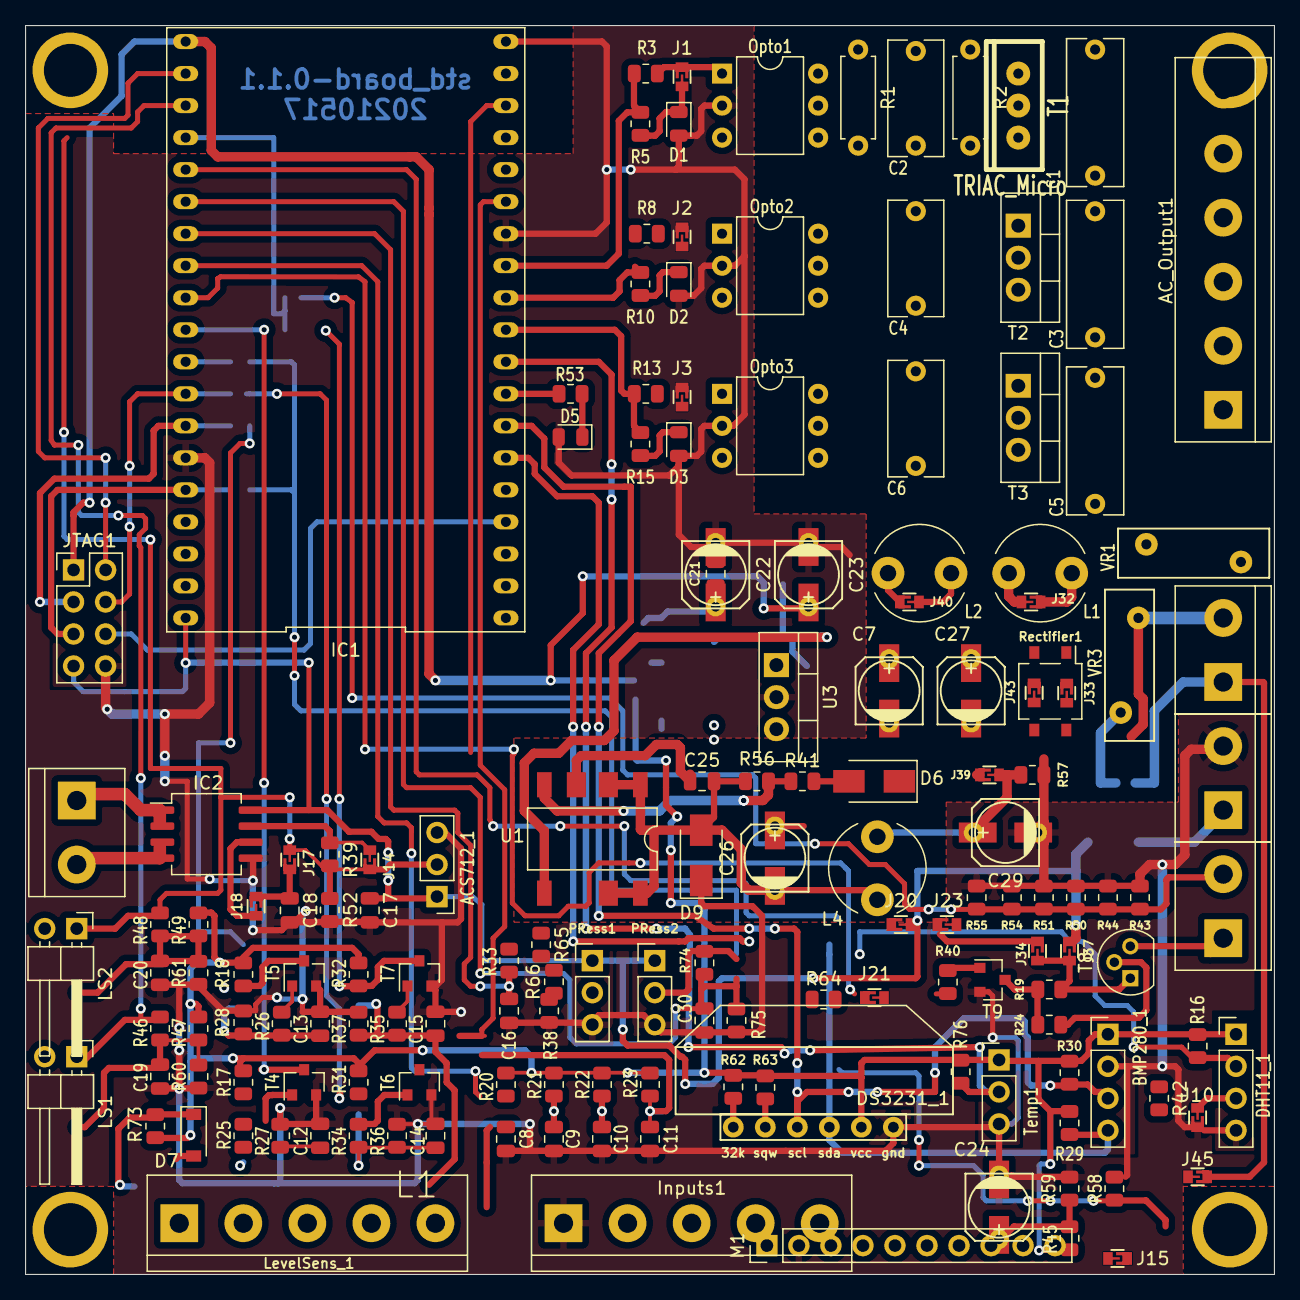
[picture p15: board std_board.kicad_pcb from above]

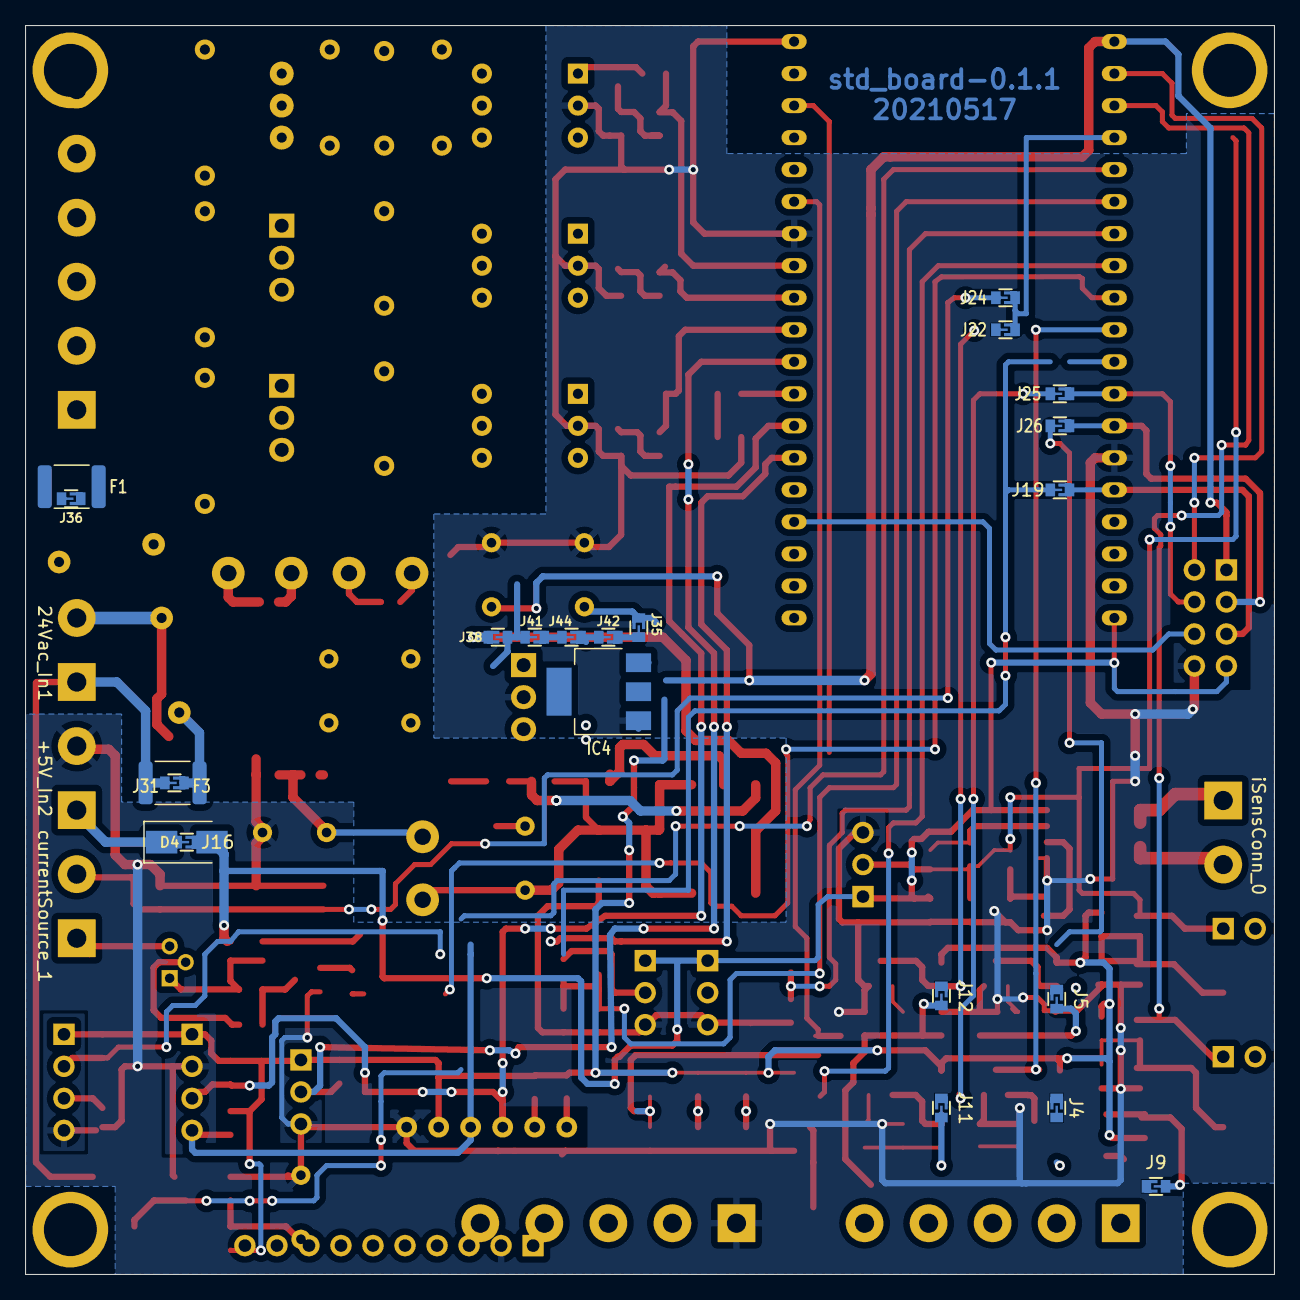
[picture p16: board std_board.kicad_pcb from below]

Board: 2 copper layers, 99.1 x 99.1 mm, 184 parts (22 on the bottom side), 87 nets.

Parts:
24Vac_In1: PowerSupply; TerminalBlock_bornier-2_P5.08mm
+5V_In2: +5V; TerminalBlock_bornier-2_P5.08mm
ACS712_1: ACS712_Module; PinHeader_1x03_P2.54mm_Vertical
AC_Output1: Driver_AC_1; TerminalBlock_bornier-6_P5.08mm
BMP280_1: BMP280; PinHeader_1x04_P2.54mm_Vertical
C1, C3, C5: 10 nF; C_Rect_L11.5mm_W4.3mm_P10.00mm_MKT
C2, C4, C6: 47 nF; C_Rect_L9.0mm_W4.2mm_P7.50mm_MKT
C7: 47 uF; C3_elec_5x4.5_pth
C8, C9, C10, C11: 47 nF; C_0805_2012Metric
C12, C13, C14, C15, C16, C30: 10 nF; C_0805_2012Metric
C17: 0.1 uF; C_0805_2012Metric
C18: 1 nF; C_0805_2012Metric
C19, C20, C21: 1 uF; C_0805_2012Metric
C22: 2.2 uF; C3_elec_5x4.5_pth
C23, C24: 22 uF; C3_elec_5x4.5_pth
C25: 100 nF; C_0805_2012Metric
C26: 10 uF; C3_elec_5x4.5_pth
C27: 4.7 uF; C3_elec_5x4.5_pth
C29: 100 uF; C3_elec_5x4.5_pth
D1, D2, D3, D5: Led_Micro; LED_0805_2012Metric
D4: Diode; D_SMA
D6: 1N4005GP; D_SMA
D7: Diode; D_SOD-123
D9: UF4005; D_SMA
DHT11_1: DHT11; PinHeader_1x04_P2.54mm_Vertical
DS3231_1: DS3231_1; DS3231_module_vertical
E1, E2, E3, E4: ScrewHole; ScrewHole_4.2mm
F1, F3: Fuse; Fuse_1812_4532Metric
IC1: ESP32; ESP32_DEVKIT
IC2: ACS712; SO-8_5.3x6.2mm_P1.27mm
IC4: AMS1117-V; SOT-223
Inputs1: CONN_5X1; TerminalBlock_bornier-5_P5.08mm
J1, J2, J3, J4, J5, J9, J11, J12, J14, J15, J17, J18, J19, J20, J21, J22, J23, J24, J25, J26, J31, J32, J33, J34, J35, J36, J37, J38, J39, J40, J41, J42, J43, J44, J45: Jumper; J_0603
J10: J_DHT11; J_0603
J16: J_PRess; J_0603
JTAG1: JTAG_CONN-06_adapted; PinHeader_2x04_P2.54mm_Vertical
L1, L2: L_Micro; L_Radial_D7.5mm_P5.00mm_Fastron_07P
L4: 1 mH; L_Radial_D7.5mm_P5.00mm_Fastron_07P
LS1, LS2: I_sens; PinHeader_1x02_P2.54mm_Horizontal
LevelSens_1: levelSensors; TerminalBlock_bornier-5_P5.08mm
M1: ADS1x15_module; PinHeader_1x10_P2.54mm_Vertical
Opto1, Opto2, Opto3: Optocoupler; DIP-6_W7.62mm
PRess1, PRess2: pressureSensor; PinHeader_1x03_P2.54mm_Vertical
R1: 330; R_Axial_DIN0207_L6.3mm_D2.5mm_P7.62mm_Horizontal
R2: 470; R_Axial_DIN0207_L6.3mm_D2.5mm_P7.62mm_Horizontal
R3, R8, R13: 680; R_0805_2012Metric
R5, R10, R15: 1 k; R_0805_2012Metric
R16, R76: 4.7 k; R_0805_2012Metric
R17, R18, R31, R32: 560 k; R_0805_2012Metric
R19: 47 k; R_0805_2012Metric
R20, R21, R22, R23, R47: 56 k; R_0805_2012Metric
R24, R39: 2.2 k; R_0805_2012Metric
R25, R26, R34, R35: 33 k; R_0805_2012Metric
R27, R28, R36, R37, R64: 220 k; R_0805_2012Metric
R29, R30: R_Micro; R_0805_2012Metric
R33, R74: 12 k; R_0805_2012Metric
R38, R65, R66, R75: 6.8 k; R_0805_2012Metric
R40: 100 k; R_0805_2012Metric
R41: 13 k; R_0805_2012Metric
R42: 1 M; R_0805_2012Metric
R43, R44, R50, R51, R54, R55: 30; R_0805_2012Metric
R45, R60: 39 k; R_0805_2012Metric
R46, R48, R52, R57, R58: 3.3 k; R_0805_2012Metric
R49: 180 k; R_0805_2012Metric
R53: 510; R_0805_2012Metric
R56: 2.05 k; R_0805_2012Metric
R59, R61: 120 k; R_0805_2012Metric
R62, R63: 10 k; R_0805_2012Metric
R73: 70 k; R_0805_2012Metric
Rectifier1: DF10S; TO-269AA
T1: TRIAC_Micro; TO-220_thm
T2, T3: TRIAC_Micro; TO-220-3_Vertical
T4, T5, T6, T7, T9: NPN_MMBT222A; SOT-23
T8: PNP_2N3906; TO-92
Temp1: DS18B20; PinHeader_1x03_P2.54mm_Vertical
U1: LNK306; PowerIntegrations_SMD-8B
U3: L7805CV; TO-220-3_Vertical
VR1, VR3: VR_Micro; RV_Disc_D12mm_W3.9mm_P7.5mm
currentSource_1: Connector_2; TerminalBlock_bornier-2_P5.08mm
iSensConn_0: sensConn; TerminalBlock_bornier-2_P5.08mm

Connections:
/1wire_Data: IC1.28 (U2_TXD/GPIO17), R76.1 (A), Temp1.2
/32K: DS3231_1.6, R62.2 (B)
/+3.3V: BMP280_1.1, C23.1, DHT11_1.1, DS3231_1.2, IC1.1 (3V3), IC4.2 (OUT), JTAG1.1 (VTref/3V3), R16.1 (A), R17.1 (A), R18.1 (A), R20.1 (A), R21.1 (A), R22.1 (A), R23.1 (A), R29.1 (A), R30.1 (A), R31.2 (B), R32.2 (B), R45.1 (A), R47.1 (A), R49.1 (A), R62.1 (A), R63.1 (A), R73.1 (A), R76.2 (B), Temp1.1
/+5V: ACS712_1.1, C17.1 (A), C21.1 (A), C22.1, D4.2 (-Cathode), IC1.19 (5V5), IC2.8, IC4.3 (IN), J16.1 (A), J35.1 (A), J37.1 (A), J42.1 (A), JTAG1.7 (+5V), M1.1, PRess1.1, PRess2.1, U3.1 (IN)
/A: C7.1, J38.2 (B), J40.1 (A), J41.2 (B), L2.1 (A)
/ADC_1: J24.2 (B), R43.2 (B), R44.2 (B), R50.2 (B), R51.2 (B), R54.2 (B), R55.2 (B), currentSource_1.2 (S2)
/B: J41.1 (A), J44.2 (B)
/C: J34.1 (A), J39.1 (A), J42.2 (B), J44.1 (A), U3.3 (OUT)
/Common: AC_Output1.5, J23.2 (B), R64.1 (A), VR1.2
/DAC_1: IC1.9 (GPIO25/ADC2_8/DAC_1), R40.1 (A)
/DHT11_data: DHT11_1.2, J19.2 (B), R16.2 (B)
/Debug_RX: IC1.27 (U2_RXD/GPIO16), R53.1 (A)
/IP+: IC2.1, IC2.2, iSensConn_0.1 (S1)
/IP-: IC2.3, IC2.4, iSensConn_0.2 (S2)
/K1_in: C8.1 (A), IC1.37 (SPI_MOSI/GPIO23), Inputs1.2, R20.2 (B)
/K1_out: IC1.31 (SPI_MISO/GPIO19_(33)), R3.1 (A), R5.1 (A)
/K2_in: C9.1 (A), IC1.36 (U0_RTS/WIRE-SDL/GPIO22), Inputs1.3, R21.2 (B)
/K2_out: IC1.30 (SPI_SCK/GPIO18_(32)), R8.2 (B), R10.1 (A)
/K3_in: C10.1 (A), IC1.33 (Wire_SDA/GPIO21_(35)), Inputs1.4, R22.2 (B)
/K3_out: IC1.29 (SPI_SS/GPIO05), R13.1 (A), R15.1 (A)
/L1_in: IC1.10 (GPIO26/ADC2_9/DAC_2), J4.1 (A), R17.2 (B), T4.3
/L1_probe: C12.1 (A), J4.2 (B), LevelSens_1.2, R25.1 (A), R27.1 (A)
/L2_in: IC1.11 (GPIO27/ADC2_7), J5.1 (A), R18.2 (B), T5.3
/L2_probe: C13.1 (A), J5.2 (B), LevelSens_1.3, R26.1 (A), R28.1 (A)
/L3_in: J11.1 (A), J25.2 (B), R31.1 (A), T6.3
/L3_probe: C14.1 (A), J11.2 (B), LevelSens_1.4, R34.1 (A), R36.1 (A)
/L4_in: J12.1 (A), J26.2 (B), R32.1 (A), T7.3
/L4_probe: C15.1 (A), J12.2 (B), LevelSens_1.5, R35.1 (A), R37.1 (A)
/Load01: AC_Output1.1, C1.2 (B), C2.2 (B), J20.1 (A), T1.1 (K)
/Load02: AC_Output1.2, C3.2 (B), C4.2 (B), T2.1
/Load03: AC_Output1.3, C5.2 (B), C6.2 (B), T3.1
/NRST: IC1.2 (RST/JTAG_RST/CHIP-PU), JTAG1.2 (nTRST)
/PRess_1: C16.1 (A), IC1.6 (GPIO35/ADC1_7), R33.2 (B), R38.1 (A), R65.1 (A)
/PRess_2: C30.1 (A), IC1.7 (GPIO32/ADC1_4), R66.1 (A), R74.2 (B), R75.1 (A)
/Power_AC_2: F1.1, T2.2, T3.2, VR1.1
/Power_AC_R: J36.2 (B), R2.1 (A), T1.2 (A)
/Power_AC_R_2: J15.1 (A), J36.1 (A)
/SCL: BMP280_1.3, DS3231_1.4, IC1.26 (ADC2_0/GPIO04), M1.3, R30.2 (B)
/SDA: BMP280_1.4, DS3231_1.3, IC1.25 (ADC2_1/GPIO00), M1.4, R29.2 (B)
/SQW: DS3231_1.5, R63.2 (B)
/T1_in: C11.1 (A), IC1.8 (GPIO33/ADC1_5/TOUCH8/XTAL32), Inputs1.5, R23.2 (B)
/TDO: IC1.23 (TDO/ADC2_3/GPIO15), JTAG1.6 (TDO)
/V_external: AC_Output1.6, J21.1 (A)
/V_input: 24Vac_In1.1 (S1), F3.2, J31.2 (B), J45.1 (A)
/iSensor1: IC1.3 (GPIO36/ADC1_0/SensVP/ADC_PA/RTCIO_0), LS1.1 (A), R46.1 (A)
/iSensor2: ACS712_1.2, J14.1 (A), J17.2 (B), J22.2 (B), LS2.1 (A), R39.2 (B), R48.1 (A), R52.1 (A)
/vSensorR: IC1.5 (GPIO34/ADC1_6/VDET-1/RTCIO4), R42.2 (B), R58.1 (A)
GND: +5V_In2.2 (S2), ACS712_1.3, BMP280_1.2, C7.2 (GND), C8.2 (B), C9.2 (B), C10.2 (B), C11.2 (B), C12.2 (B), C13.2 (B), C14.2 (B), C15.2 (B), C16.2 (B), C17.2 (B), C18.2 (B), C19.2 (B), C20.2 (B), C21.2 (B), C22.2 (GND), C23.2 (GND), C24.2 (GND), C27.2 (GND), C29.2 (GND), C30.2 (B), D1.2, D2.2, D3.2, D5.2, D9.1 (+Anode), DHT11_1.4, DS3231_1.1, IC1.14 (GND), IC1.32 (GND_(34)), IC1.38 (GND), IC2.5, IC4.1 (GND), Inputs1.1, J10.1 (A), J43.1 (A), JTAG1.8 (GND), M1.2, Opto1.2, Opto2.2, Opto3.2, PRess1.3, PRess2.3, R27.2 (B), R28.2 (B), R36.2 (B), R37.2 (B), R38.2 (B), R43.1 (A), R44.1 (A), R50.1 (A), R51.1 (A), R52.2 (B), R54.1 (A), R55.1 (A), R57.2 (B), R59.2 (B), R60.2 (B), R61.2 (B), R65.2 (B), R66.2 (B), R75.2 (B), Rectifier1.2 (Negative), T4.2, T5.2, T6.2, T7.2, T9.2, Temp1.3, U3.2 (GND)
unnamed: 24Vac_In1.2 (S2), J43.2 (B), Rectifier1.3 (AC_Input)
unnamed: +5V_In2.1 (S1), D4.1 (+Anode), J16.2 (B)
unnamed: C2.1 (A), R1.2 (B), R2.2 (B)
unnamed: C18.1 (A), J17.1 (A), J18.1 (A)
unnamed: C19.1 (A), LS1.2 (B), R46.2 (B), R47.2 (B), R60.1 (A)
unnamed: C20.1 (A), LS2.2 (B), R48.2 (B), R49.2 (B), R61.1 (A)
unnamed: C25.1 (A), U1.3 (BP)
unnamed: C25.2 (B), C26.2 (GND), D9.2 (-Cathode), L4.1 (A), R56.2 (B), U1.1 (S), U1.2 (S), U1.7 (S), U1.8 (S)
unnamed: J1.2 (B), R5.2 (B)
unnamed: J2.2 (B), R10.2 (B)
unnamed: J3.2 (B), R15.2 (B)
unnamed: C29.1, D6.1 (+Anode), J39.2 (B), L4.2 (B), R57.1 (A)
unnamed: C26.1, D6.2 (-Cathode), R41.2 (B)
unnamed: D7.1 (+Anode), J9.2 (B), R73.2 (B)
unnamed: D7.2 (-Cathode), J9.1 (A), LevelSens_1.1
unnamed: J31.1 (A), J32.2 (B), L1.2 (B)
unnamed: F3.1, VR3.1
unnamed: J14.2 (B), R39.1 (A)
unnamed: J1.1 (A), R3.2 (B)
unnamed: J2.1 (A), R8.1 (A)
unnamed: J3.1 (A), R13.2 (B)
unnamed: J15.2 (B), J20.2 (B), J21.2 (B), J45.2 (B), R42.1 (A)
unnamed: C24.1, J23.1 (A), R45.2 (B), R58.2 (B), R59.1 (A), R64.2 (B)
unnamed: J32.1 (A), J33.2 (B), L1.1 (A), Rectifier1.4 (AC_Input)
unnamed: C27.1, J33.1 (A), J40.2 (B), L2.2 (B), Rectifier1.1 (Positive)
unnamed: J34.2 (B), J37.2 (B), R19.2 (B), T8.1 (E)
unnamed: J38.1 (A), U1.5 (D)
unnamed: Opto2.4, T2.3
unnamed: Opto3.4, T3.3
unnamed: R19.1 (A), R24.2 (B)
unnamed: R24.1 (A), T8.2 (B)
unnamed: PRess1.2, R33.1 (A)
unnamed: R41.1 (A), R56.1 (A), U1.4 (FB)
unnamed: PRess2.2, R74.1 (A)
unnamed: T8.3 (C), currentSource_1.1 (S1)
P03: IC1.4 (GPIO39/ADC1_3/SensVN/RTCIO-3/ADC-PA), J22.1 (A), J24.1 (A)
P12: IC1.12 (GPIO14/ADC2_6/TMS), J25.1 (A), JTAG1.4 (TMS)
P13: IC1.13 (GPIO12/ADC2_5/TDI), J26.1 (A), JTAG1.3 (TDI)
P15: IC1.15 (GPIO13/ADC2_4/TCK), J19.1 (A), JTAG1.5 (TCK)

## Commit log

2021-03-10 gerber updated on 20210310-2044
    [std_board-B_Cu.gbr, std_board-B_Mask.gbr, std_board-B_Paste.gbr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]
2021-03-11 Gerber files added
    [std_board-B_Cu.gbl, std_board-B_Mask.gbs, std_board-B_SilkS.gbo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]
2021-05-28 updates on circuit board and readme file
    [LevelSensor.sch, std_board.sch]
2021-05-28 AC load explanation
    [std_board.kicad_pcb, std_board.sch]
2021-05-28 pin map Figure updated
2021-07-19 TODO list added on REAME.md
    [ADC_Current.sch, ADC_Voltage.sch, TRIAC_DIAC.sch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]
2021-07-19 voltage sensor new structure part 1
    [std_board.sch]
2021-09-02 voltage sensor: calculated resistors
    [ADC_Voltage.sch, fonte_corrente.sch, std_board.kicad_pcb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]
2021-09-11 fixed voltage divider of pressure circuit design
    [press_sensor_voltage_divider.sch, std_board.kicad_pcb, std_board.sch]
2021-09-17 recalculated ADC voltage divider measurement
    [ADC_Voltage.sch, std_board.kicad_pcb, std_board.sch]
2021-09-22 updated board image with pinmap description
    [std_board.kicad_pcb]
2021-09-22 updated pin map table
2021-09-24 recalculated current sensor resistors and changed pins and jumps of levels and sensors
    [ADC_Current.sch, ADC_Voltage.sch, ADC_current.sch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]
2022-11-03 added new triac circuit upgrade to soft starter
    [press_sensor_voltage_divider.sch, pricelist.xlsx, std_board.csv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]
2023-08-31 board update some documentation of pinout link with description
    [ADC_Voltage.sch, ADC_current.sch, LevelSensor.sch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]
2023-12-27 current sensor 1 added resistors for voltage divider
    [std_board.kicad_pcb, std_board.kicad_sch]
2024-02-16 changed pi filter values at input of power supply
    [std_board.csv, std_board.kicad_sch]
2024-02-16 moved backups to another place
    [std_board.kicad_pcb, std_board.kicad_sch]
